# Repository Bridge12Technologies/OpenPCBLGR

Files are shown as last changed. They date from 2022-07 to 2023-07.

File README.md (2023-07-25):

# OpenPCBLGR
## An Open-Source Loop-Gap Resonator for X-Band EPR Spectroscopy
### Rev 1.0

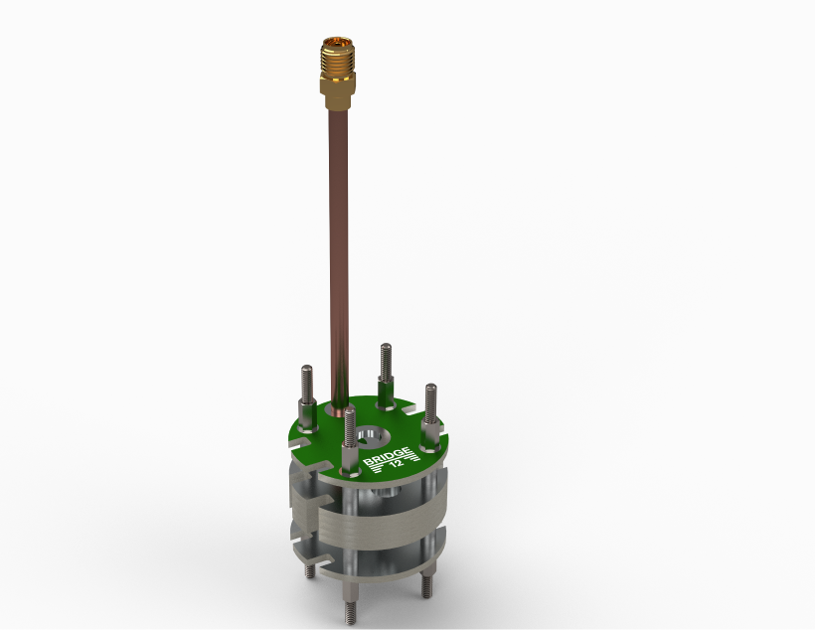
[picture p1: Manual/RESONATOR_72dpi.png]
OpenPCBLGR Resonator


## Contents
This repository contains CAD files (solidworks and STEP files), 3d printer files (STL), KiCAD project files, 
PCB gerber files, bill of materials (BOM), and the assembly manual.

In 2023 Thorsten Maly [(@thmaly)](https://twitter.com/thmaly) presented a workshop at the 62<sup>nd</sup> [Rocky Mountain Conference](https://rockychem.com/) on the design and assembly of the OpenPCBLGR. The presentation is available in the manuals folder of the the repository or for download on the [OpenPCBLGR Webpage](https://www.bridge12.com/learn/open-pcb-lgr/).

## Assembly Manual
The assembly manual for Rev1.0 is found in the [Assembly Manual](Manual/PCB%20LGR%20Assembly%20Instructions%20Rev1.0.docx) word document.

## Ordering PCBs
If no modifications to the resonator are required, the gerber files can be uploaded directly to the manufacturer's website ([JLCPCB](https://jlcpcb.com/)).

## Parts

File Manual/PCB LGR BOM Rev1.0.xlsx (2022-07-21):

BOM for PCB LGR
Rev 1.0
2022-07-15
ITEM NO. | PART NO. | DESCRIPTION | VENDOR | QUANTITY | COST PER UNIT | EXTENDED PRICE | LINK
1 | 121003116 | PCB LGR | B12T | 5 | 1.00 | 5.00
2 | 121003117 | PCB LGR TOP | B12T | 1 | 1.00 | 1.00
3 | 121003118 | PCB LGR BOTTOM | B12T | 1 | 1.00 | 1.00
4 | 92511A129 | SPACER #2 0.250 LG | MCMASTER | 8 | 1.72 | 13.76 | Link to McMaster (https://www.mcmaster.com/92511A129/)
5 | 91780A023 | STANDOFF 2-56 0.250 LG | MCMASTER | 16 | 0.44 | 7.04 | Link to McMaster (https://www.mcmaster.com/91780A023/)
6 | 93225A413 | THREADED ROD #2 2.000 LG | MCMASTER | 4 | 0.69 | 2.76 | Link to McMaster (https://www.mcmaster.com/93225A413/)
7 | ACX2083-ND | CONN SMA JACK STR 50 OHM SOLDER | DIGIKEY | 1 | 6.05 | 6.05 | Link to DigiKey (https://www.digikey.com/en/products/detail/amphenol-rf/132104/2628823)
8 | FMBC007 | UT-141C COAX 3.000 LG | FAIRVIEW | 1 | 19.79 | 19.79 | Link to Fairview Microwave (https://www.fairviewmicrowave.com/141-low-loss-semirigid-coax-cable-copper-straight-fmbc007-p.aspx)
9 | 121003119 | PCB COUPLING LOOP 4MM-6MM | B12T | 1 | 1.00 | 1.00
10 | 76555A721 | COPPER TAPE 0.250 WD 4.000 LG | MCMASTER | 2 | 8.91 | 17.82 | Link to McMaster (https://www.mcmaster.com/76555A721/)
11 | 76555A725 | COPPER TAPE 2.000 WD 6.000 LG | MCMASTER | 1 | 50.61 | 50.61 | Link to McMaster (https://www.mcmaster.com/76555A725/)
12 | 92185A083 | SCREW 2-56 SOCKET HEAD 0.500 LG | MCMASTER | 4 | 0.15 | 0.61 | Link to McMaster (https://www.mcmaster.com/92185A083/)
13 | 121003107 | PCB LGR SHIELD | B12T | 1 | 0.00 | 0.00
14 | 121003108 | PCB LGR SHIELD TOP | B12T | 1 | 0.00 | 0.00
15 | 121003143 | PCB LGR SHIELD BOTTOM | B12T | 1 | 0.00 | 0.00
16 | 121003110 | PCB LGR TOP SUPPORT | B12T | 1 | 0.00 | 0.00
17 | 2328-30SNSP.125-ND | 30 AWG MAGNET WIRE | DIGIKEY | 1 | 11.26 | 11.26 | Link to DigiKey (https://www.digikey.com/en/products/detail/remington-industries/30SNSP-125/11614448)
18 | 2057-RF1-106-D-00-50-HDW-ND | BNC STRAIGHT BULKHEAD SKT 50 OHM | DIGIKEY | 1 | 1.48 | 1.48 | Link to DigiKey (https://www.digikey.com/en/products/detail/adam-tech/RF1-106-D-00-50-HDW/9830449)

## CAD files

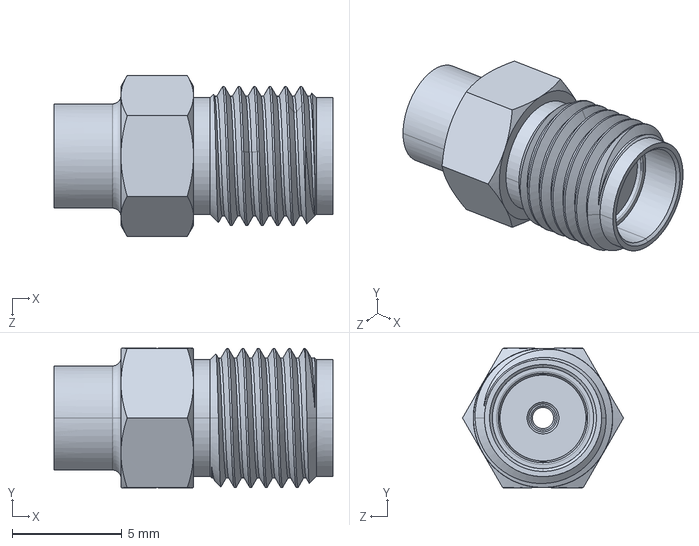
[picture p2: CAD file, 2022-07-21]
Model/901-9704.SLDPRT
12.7 x 6.35 x 7.33 mm

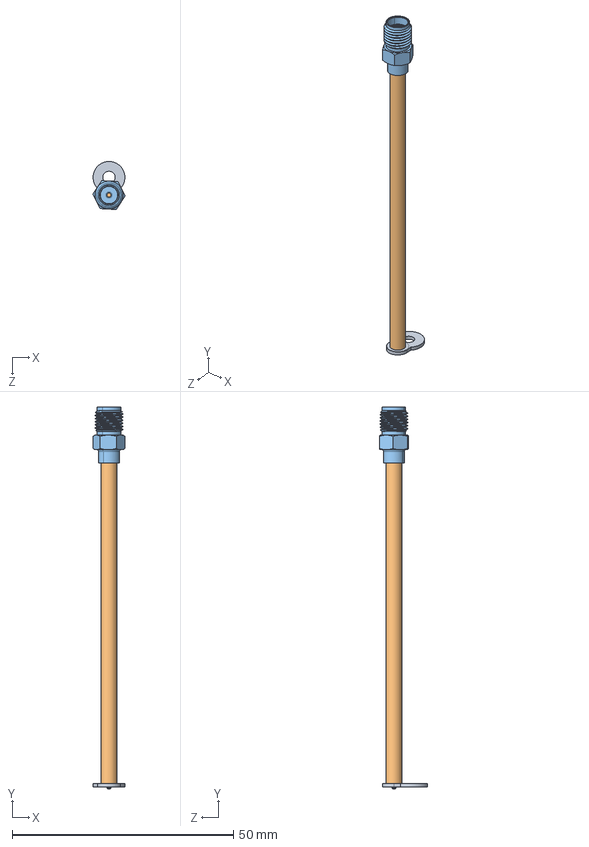
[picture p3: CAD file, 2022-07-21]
Model/122001546.SLDASM
7.32 x 86.4 x 10.9 mm

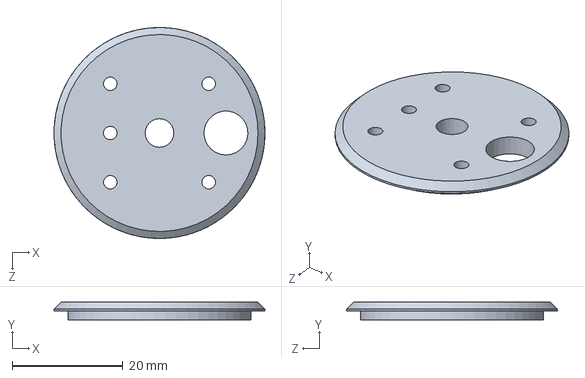
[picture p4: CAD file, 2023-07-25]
Model/121003108.SLDPRT
38.1 x 3.17 x 38.1 mm

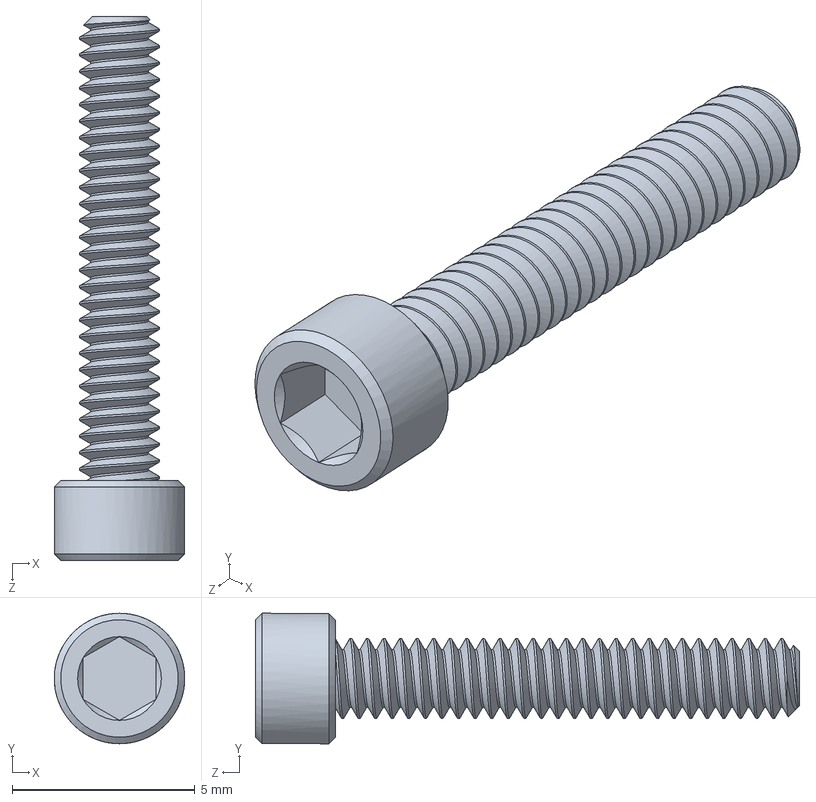
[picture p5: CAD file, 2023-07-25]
Model/92185A083.SLDPRT
3.57 x 3.57 x 14.9 mm

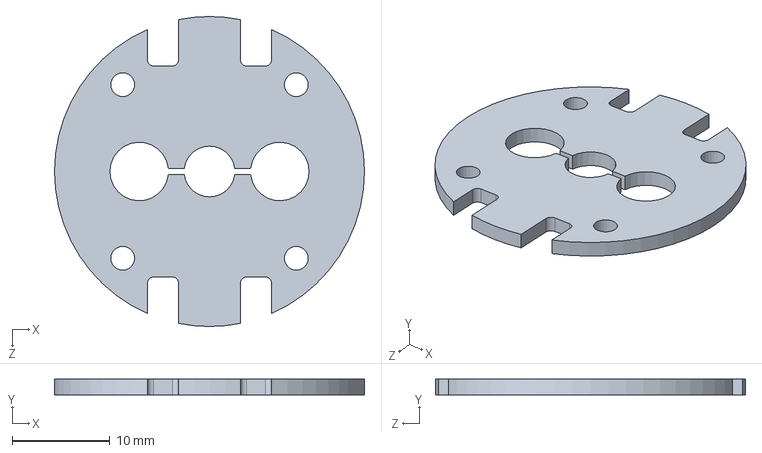
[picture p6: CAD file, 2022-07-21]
Model/121003116.SLDPRT
31.8 x 1.60 x 31.8 mm

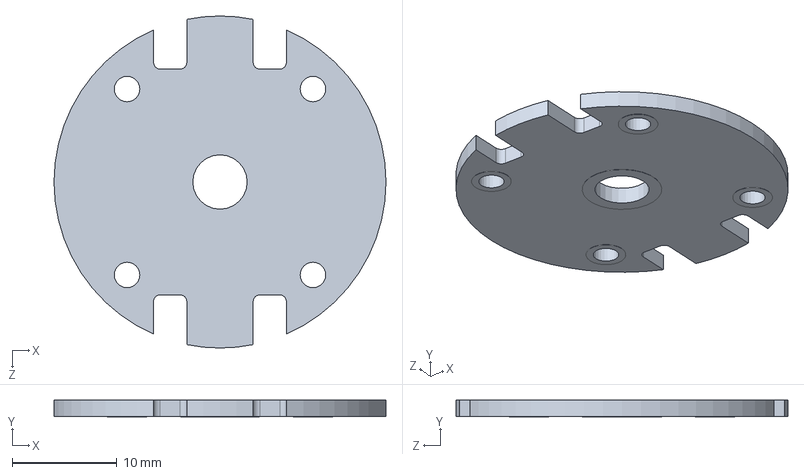
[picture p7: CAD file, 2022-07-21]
Model/121003118.SLDPRT
31.8 x 1.63 x 31.8 mm

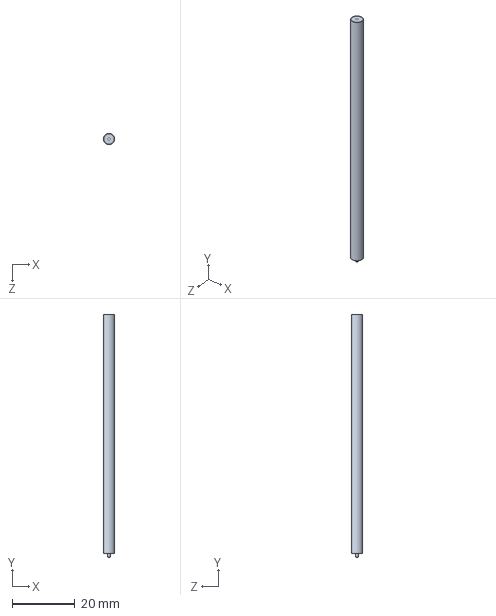
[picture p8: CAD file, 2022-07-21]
Model/121003122.SLDPRT
3.58 x 77.5 x 3.58 mm

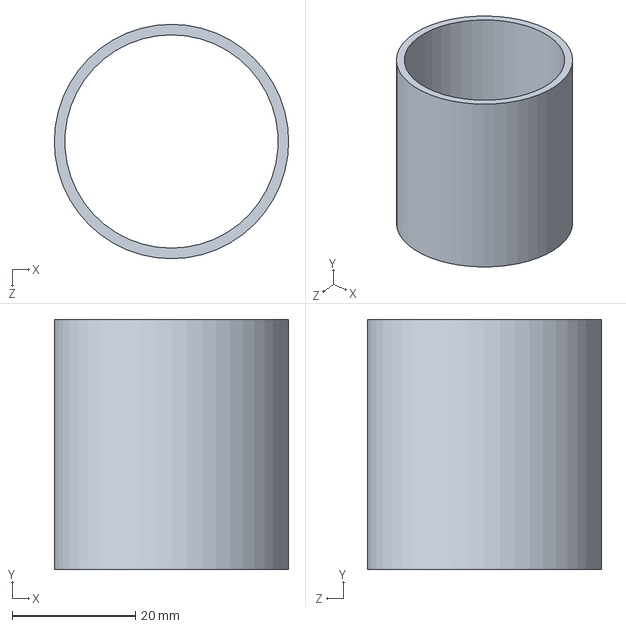
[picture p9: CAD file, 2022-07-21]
Model/121003107.SLDPRT
38.1 x 40.6 x 38.1 mm

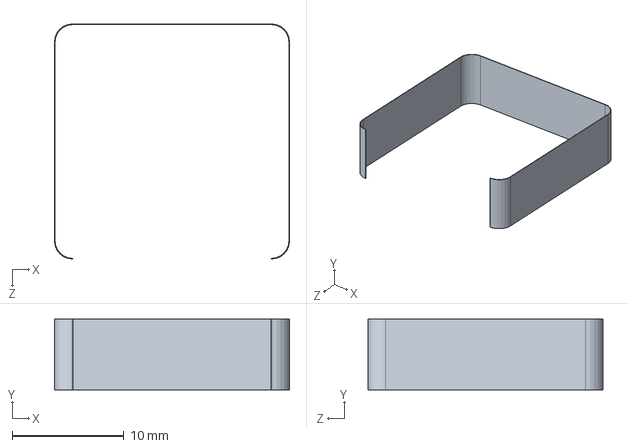
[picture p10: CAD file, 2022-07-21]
Model/121003139.SLDPRT
21.1 x 6.35 x 21.1 mm

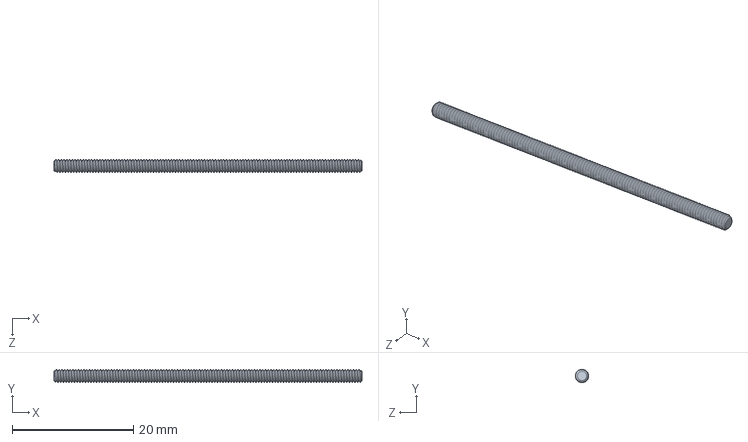
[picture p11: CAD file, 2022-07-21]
Model/93225A413.SLDPRT
50.8 x 2.18 x 2.18 mm

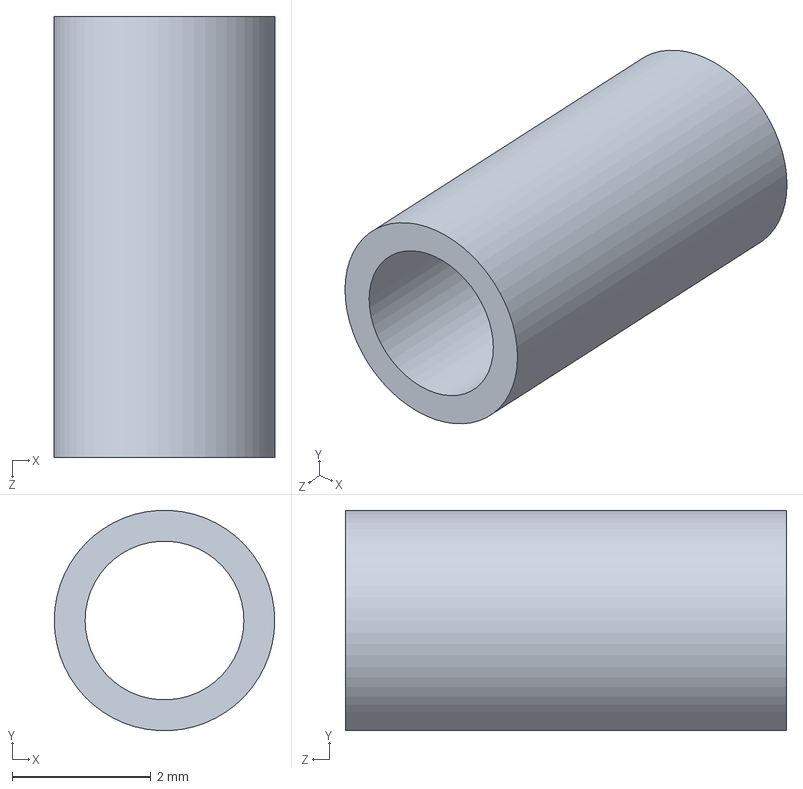
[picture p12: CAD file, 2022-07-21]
Model/92511A129.SLDPRT
3.17 x 3.17 x 6.35 mm

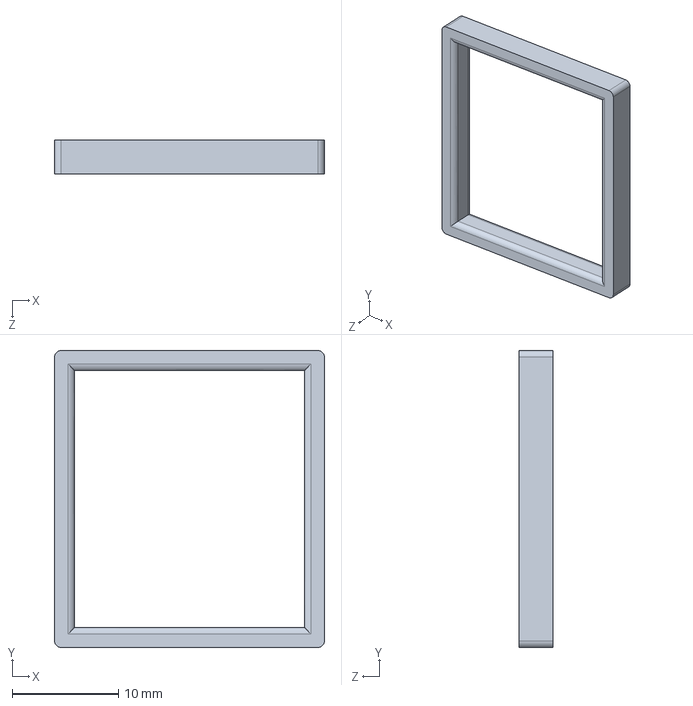
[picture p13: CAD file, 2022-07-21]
Model/121003138.SLDPRT
25.4 x 27.9 x 3.17 mm

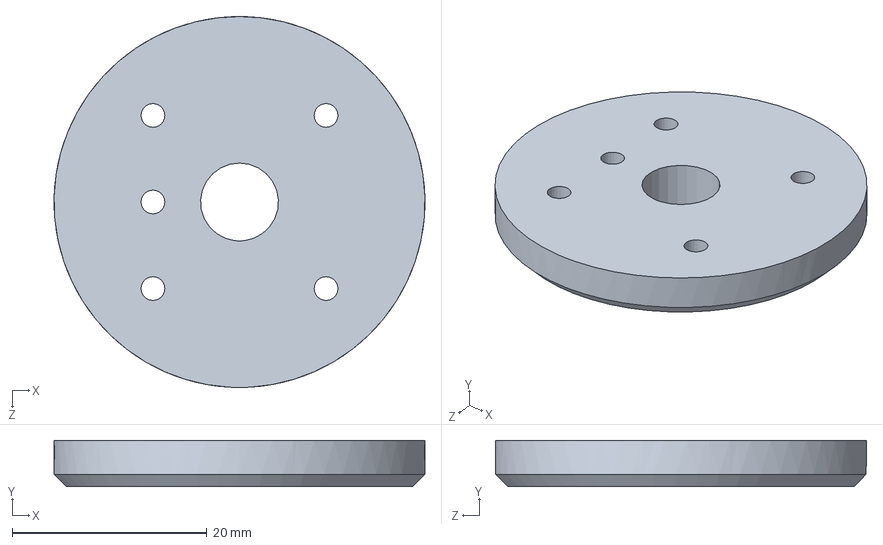
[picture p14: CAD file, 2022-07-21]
Model/121003143.SLDPRT
38.1 x 4.76 x 38.1 mm

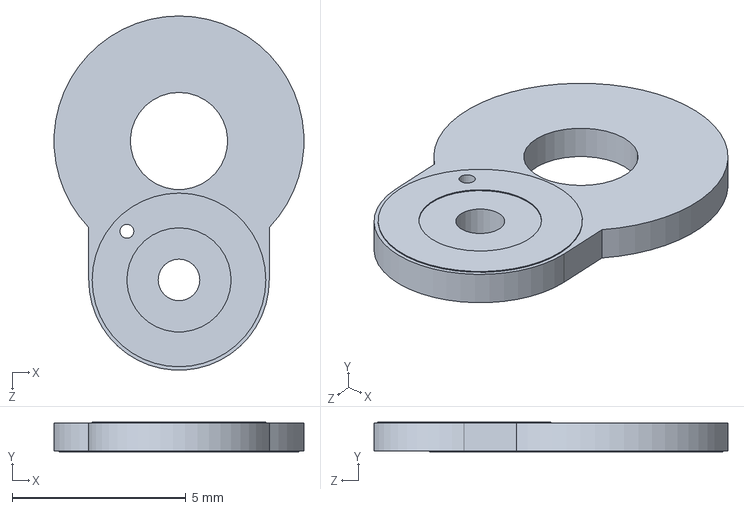
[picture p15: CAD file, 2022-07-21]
Model/121003119.SLDPRT
7.19 x 0.851 x 10.2 mm

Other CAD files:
Model/121003117.SLDPRT
Model/91780A023.SLDPRT
Model/121003110.SLDPRT
Model/121003107.STL
Model/121003108.STL
Model/121003110.STL
Model/121003143.STL

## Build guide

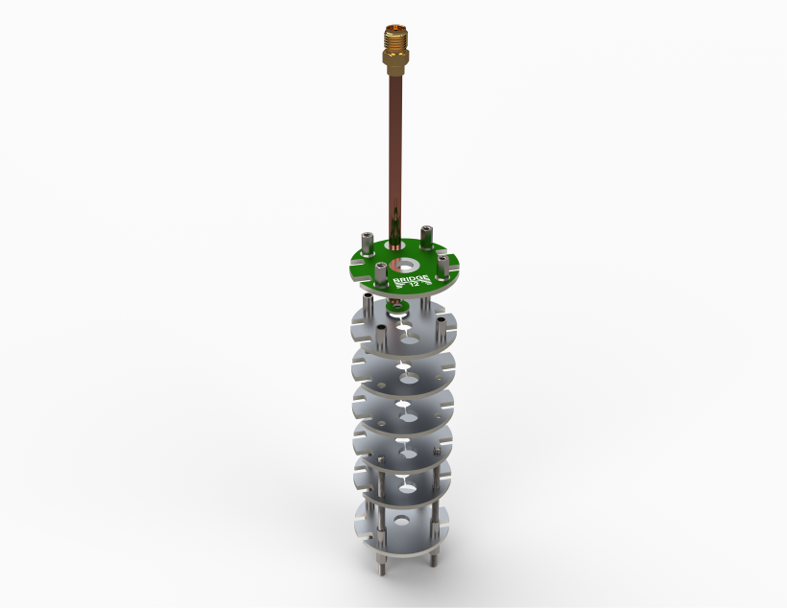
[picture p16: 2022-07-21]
Manual/RESONATOR EXPLODED_72dpi.png

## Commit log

2022-07-14 Adding CAD Models for PCB LGR
    Solid Works Model, Step file, STL files added
    [121003107.SLDPRT, 121003107.STL, 121003108.SLDPRT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]
2022-07-15 Adding KiCAD Footprint Library Files
    Adding 3L2G LGR footprint
    Adding B12T Logo
2022-07-15 Adding X-Band LGR KiCAD files
    [X-Band_EPR_LGR.kicad_pcb, X-Band_EPR_LGR.sch]
2022-07-15 Adding X-Band LGR TOP KiCAD files
    [X-Band_EPR_LGR_TOP.kicad_pcb, X-Band_EPR_LGR_TOP.sch]
2022-07-15 Adding LGR BOTTOM and COUPLING LOOP
    [4mm_6mm_COUPLING_LOOP.kicad_pcb, 4mm_6mm_COUPLING_LOOP.sch, X-Band_EPR_LGR_BOTTOM.kicad_pcb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]
2022-07-15 Updated B12T Logo on PCB LGR TOP
    [X-Band_EPR_LGR_TOP.kicad_pcb]
2022-07-15 Updated B12T Logo for PCB LGR BOTTOM
    [X-Band_EPR_LGR_BOTTOM.kicad_pcb]
2022-07-15 Updating footprint library reference for PCB LGR
    [X-Band_EPR_LGR.kicad_pcb, X-Band_EPR_LGR.sch]
2022-07-15 Adding Gerbers for PCB LGR
    [X-Band_EPR_LGR-B_Cu.gbr, X-Band_EPR_LGR-B_Mask.gbr, X-Band_EPR_LGR-B_Paste.gbr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]
2022-07-15 Updated gerbers directory
    [X-Band_EPR_LGR.kicad_pcb]
2022-07-15 Added Gerbers for PCB LGR BOTTOM
    [X-Band_EPR_LGR_BOTTOM-B_Cu.gbr, X-Band_EPR_LGR_BOTTOM-B_Mask.gbr, X-Band_EPR_LGR_BOTTOM-B_Paste.gbr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]
2022-07-15 Adding Gerbers for PCB LGR TOP
    [X-Band_EPR_LGR_TOP-B_Cu.gbr, X-Band_EPR_LGR_TOP-B_Mask.gbr, X-Band_EPR_LGR_TOP-B_Paste.gbr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]
2022-07-15 Adding Gerbers for 4mm 6mm COUPLING LOOP
    [4mm_6mm_COUPLING_LOOP-B_Cu.gbr, 4mm_6mm_COUPLING_LOOP-B_Mask.gbr, 4mm_6mm_COUPLING_LOOP-B_Paste.gbr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]
2022-07-15 Adding BOM Excel Spreadsheet
    [PCB LGR BOM Rev1.0.xlsx]
2022-07-15 Adding First Version of Assembly Instructions
    Word document
2022-07-16 Adjusting board height of coupling loop PCB
    [4mm_6mm_COUPLING_LOOP.kicad_pcb]
2022-07-18 Updating Assembly Manual and BOM
    [PCB LGR BOM Rev1.0.xlsx]
2022-07-18 Reformatted table
    [PCB LGR BOM Rev1.0.xlsx]
2022-07-18 Updated Assembly Manual
2022-07-18 Minor Changes to Assembly Manual
2022-07-21 Removing old assembly manual
2022-07-21 Renaming assembly manual back to Rev1.0
2022-08-12 Adding chamfer to coupling loop support
    Making part easier to remove from print bed
    [121003110.STL]
2022-10-26 Updates to 3d printed parts for ease of printing
    [121003108.SLDPRT, 121003108.STL, 92185A083.SLDPRT]
